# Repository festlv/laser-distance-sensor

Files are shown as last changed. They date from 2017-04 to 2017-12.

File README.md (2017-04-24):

Laser distance sensor
-----------------------

Firmware and hardware design for short-range laser distance sensor.

Preliminary feature list:
  
  * Based on [ST VL53L0X ToF distance sensor](http://www.st.com/en/imaging-and-photonics-solutions/vl53l0x.html),
  * Multiple ranging profiles/modes (default, high accuracy, long range),
  * Up to 2m range (indoors) in long range mode,
  * +/- 3mm accuracy (indoors) in hight accuracy mode,
  * On-board power regulation for 3.3-5.5V input,
  * On-board microcontroller [STM32F042](http://www.st.com/en/microcontrollers/stm32f042f6.html)
  * USB (CDC) and TTL serial outputs,
  * 24x24mm size, M3 mounting holes.

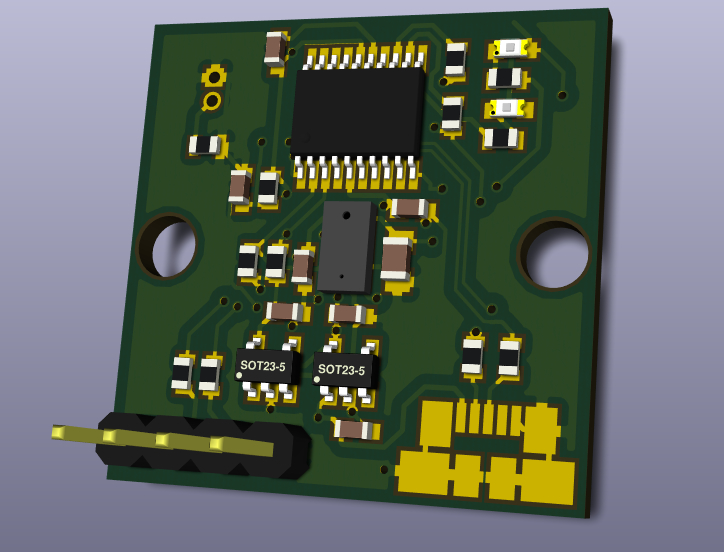
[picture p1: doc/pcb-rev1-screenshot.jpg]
Rev1 PCB render


HERE BE DRAGONS
===================

This project is WIP. Specs might be inaccurate, hardware might let out smoke,
firmware might not compile.

Current status
=================

Hardware: first prototypes have been ordered.
Firmware: waiting on hardware.

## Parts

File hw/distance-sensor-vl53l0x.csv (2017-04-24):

Reference | Value | Footprint | Datasheet | Have on hand | Ordered
U3 | VL53L0X | _sensors:VL53L0X |  | N | Y
C6 | 0.1uF | Capacitors_SMD:C_0603 |  | Y
C7 | 4.7uF | Capacitors_SMD:C_0805 |  | Y
R9 | 4K7 | Resistors_SMD:R_0603 |  | Y
R10 | 4K7 | Resistors_SMD:R_0603 |  | Y
U1 | STM32F042F6Px | Housings_SSOP:TSSOP-20_4.4x6.5mm_Pitch0.65mm |  | N | Y
C3 | 0.1uF | Capacitors_SMD:C_0603 |  | Y
C4 | 1uF | Capacitors_SMD:C_0603 |  | Y
R2 | 4K7 | Resistors_SMD:R_0603 |  | Y
C1 | 0.1uF | Capacitors_SMD:C_0603 |  | Y
J3 | CONN_02X05 | pin_headers_1.27mm:Pin_Header_1.27mm_2x5 |  | Y
R1 | 4K7 | Resistors_SMD:R_0603 |  | Y
R5 | 220R | Resistors_SMD:R_0603 |  | Y
D1 | LED | LEDs:LED_0603 |  | Y
R6 | 220R | Resistors_SMD:R_0603 |  | Y
D2 | LED | LEDs:LED_0603 |  | Y
J2 | USB_OTG | Connectors_Molex:USB_Micro-B_Molex_47346-0001 |  | Y
R3 | 22R | Resistors_SMD:R_0603 |  | Y
R4 | 22R | Resistors_SMD:R_0603 |  | Y
U2 | MIC5504-3.3 | TO_SOT_Packages_SMD:SOT-23-5 |  | N | Y
C2 | 1uF | Capacitors_SMD:C_0603 |  | Y
C5 | 1uF | Capacitors_SMD:C_0603 |  | Y
J1 | DFU | Pin_Headers:Pin_Header_Straight_1x02_Pitch1.27mm |  | Y
J4 | UART | Pin_Headers:Pin_Header_Straight_1x04_Pitch2.54mm |  | Y
R12 | 220R | Resistors_SMD:R_0603 |  | Y
R11 | 220R | Resistors_SMD:R_0603 |  | Y
R8 | 4K7 | Resistors_SMD:R_0603 |  | Y
R7 | 4K7 | Resistors_SMD:R_0603 |  | Y
U4 | MIC5504-2.8 | TO_SOT_Packages_SMD:SOT-23-5 |  | N | Y
C8 | 1uF | Capacitors_SMD:C_0603 |  | Y

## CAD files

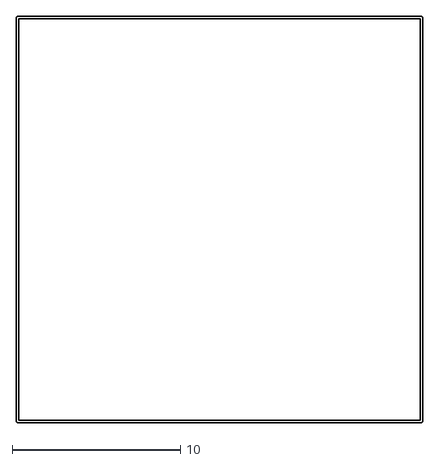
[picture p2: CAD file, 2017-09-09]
hw/out/distance-sensor-vl53l0x-Edge.Cuts.dxf
24.2 x 24.2

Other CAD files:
hw/out/distance-sensor-vl53l0x-F.Paste.dxf

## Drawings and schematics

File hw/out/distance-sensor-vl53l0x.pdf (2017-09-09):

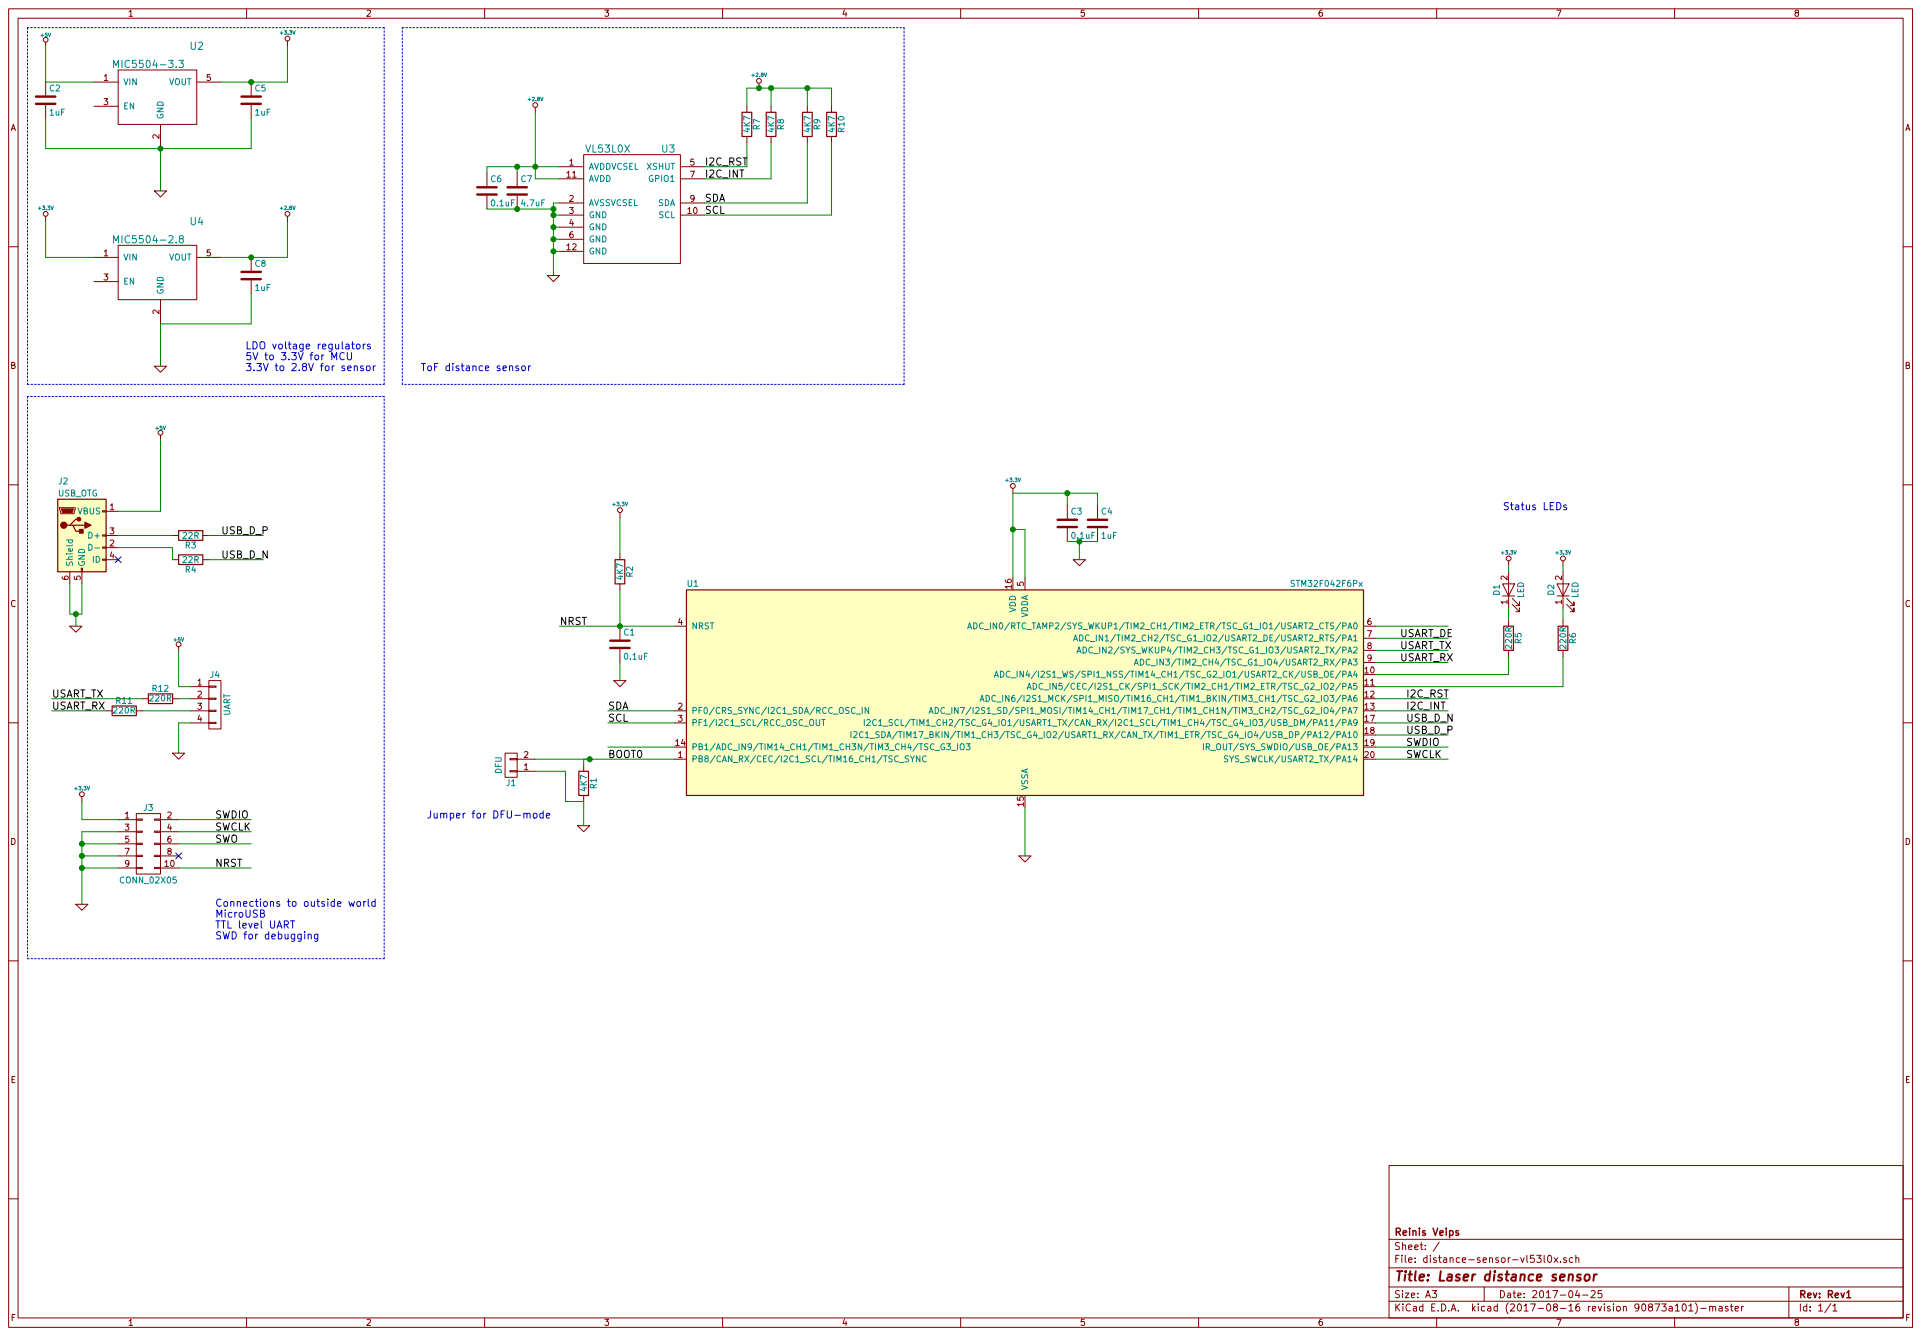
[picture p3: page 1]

3.3V to 2.8V for sensor Connections to outside world

ToF distance sensor Jumper for DFU-mode

USART_DE
USART_TX

I2C_RST
I2C_INT

5 | 6 SWO
9 | 10

MicroUSB
TTL level UART SWD for debugging

Id: 1/1 Title: Laser distance sensor File: distance-sensor-vl53l0x.sch Sheet: / Reinis Veips

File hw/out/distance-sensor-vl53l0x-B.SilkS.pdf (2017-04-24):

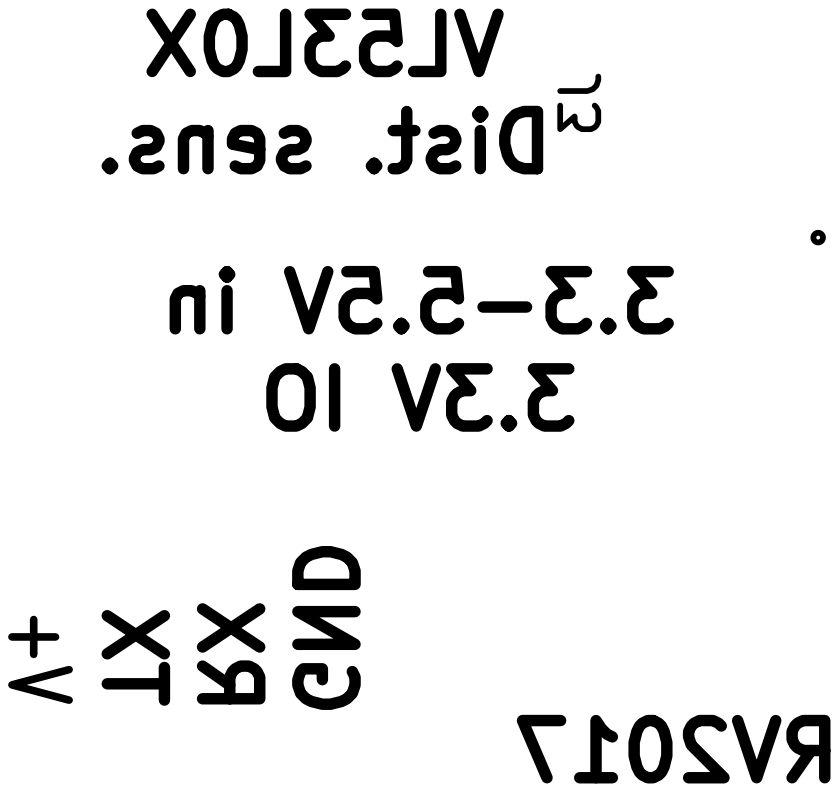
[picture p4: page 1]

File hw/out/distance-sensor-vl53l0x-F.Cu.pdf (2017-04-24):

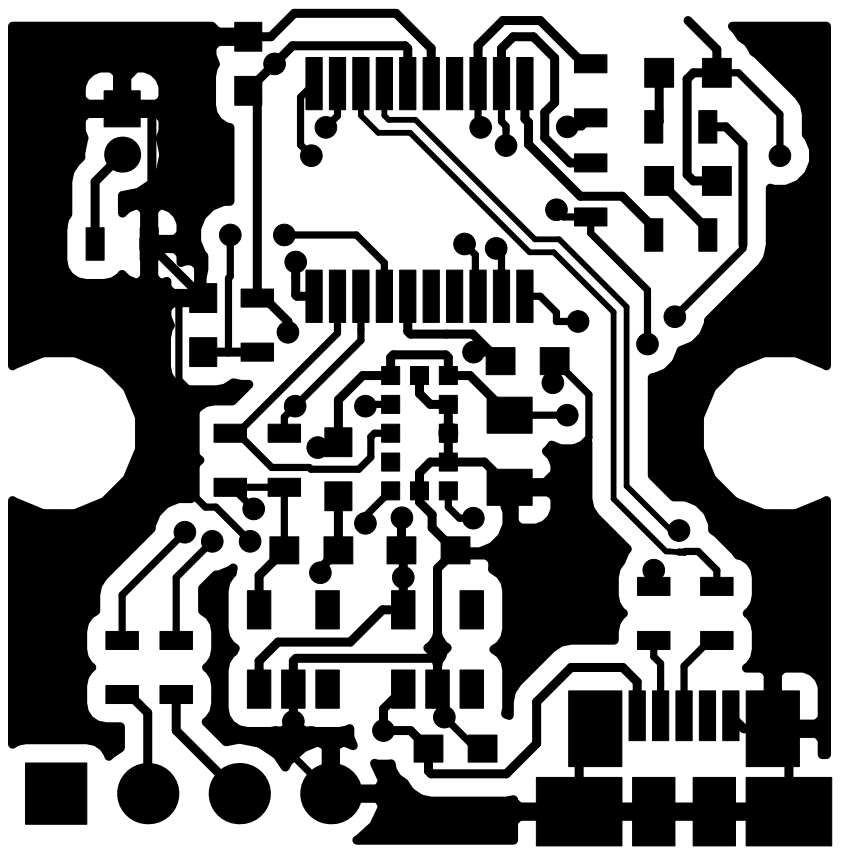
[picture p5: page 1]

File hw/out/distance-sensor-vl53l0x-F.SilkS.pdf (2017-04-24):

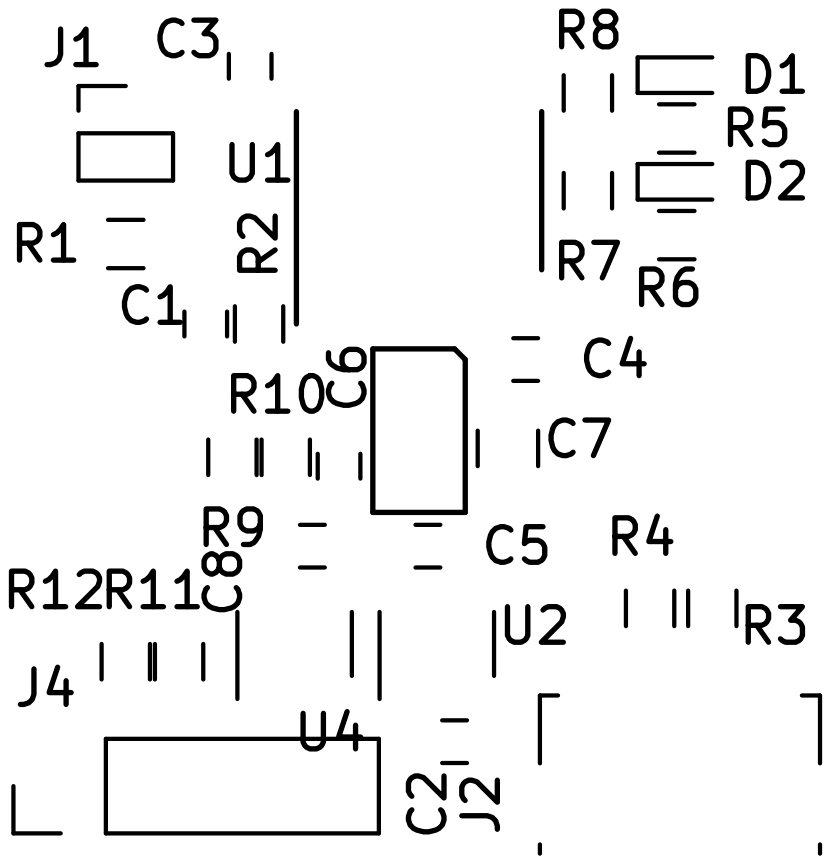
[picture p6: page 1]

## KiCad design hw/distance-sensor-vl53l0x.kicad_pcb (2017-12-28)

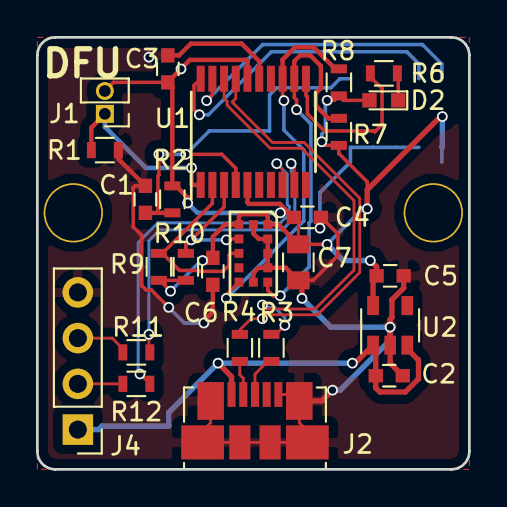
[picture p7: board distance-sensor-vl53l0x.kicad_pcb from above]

Board: 2 copper layers, 24.0 x 24.0 mm, 28 parts (1 on the bottom side), 21 nets.

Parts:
C1, C3, C6: 0.1uF; C_0603
C2, C4, C5: 1uF; C_0603
C7: 4.7uF; C_0805
D2: LED; LED_0603
J1: DFU; Pin_Header_Straight_1x02_Pitch1.27mm
J2: USB_OTG; USB_Micro-B_Molex_47346-0001
J3: CONN_02X05; Pin_Header_1.27mm_2x5
J4: UART; Pin_Header_Straight_1x04_Pitch2.54mm
J101, J102: TEST_1P; Mounting_hole_3mm
R1, R2, R7, R8, R9, R10: 4K7; R_0603
R3, R4: 22R; R_0603
R6, R11, R12: 220R; R_0603
U1: STM32F042F6Px; TSSOP-20_4.4x6.5mm_Pitch0.65mm
U2: MIC5504-3.3; SOT-23-5
U3: VL53L0X

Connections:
+3.3V: C3.1, C4.1, C5.1, C6.1, C7.1, D2.2, J1.2, J3.1, R2.1, R7.1, R8.1, R9.1, R10.1, U1.5, U1.16, U2.5, U3.1, U3.11
+5V: C2.1, J2.1, J4.1, U2.1, U2.3
/BOOT0: J1.1, R1.1, U1.1
/I2C_INT: R8.2, U1.13, U3.7
/I2C_RST: R7.2, U1.12, U3.5
/NRST: C1.1, J3.10, R2.2, U1.4
/SCL: R10.2, U1.3, U3.10
/SDA: R9.2, U1.2, U3.9
/SWCLK: J3.4, U1.20
/SWDIO: J3.2, U1.19
/USART_RX: R11.1, U1.9
/USART_TX: R12.1, U1.8
/USB_D_N: R4.1, U1.17
/USB_D_P: R3.1, U1.18
GND: C1.2, C2.2, C3.2, C4.2, C5.2, C6.2, C7.2, J2.5, J2.6, J3.3, J3.5, J3.7, J3.9, J4.4, R1.2, U1.15, U2.2, U3.2, U3.3, U3.4, U3.6, U3.12
unnamed: D2.1, R6.1
unnamed: J2.2, R4.2
unnamed: J2.3, R3.2
unnamed: J4.2, R12.2
unnamed: J4.3, R11.2
unnamed: R6.2, U1.11

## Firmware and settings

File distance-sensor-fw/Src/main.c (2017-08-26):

/**
  ******************************************************************************
  * File Name          : main.c
  * Description        : Main program body
  ******************************************************************************
  * This notice applies to any and all portions of this file
  * that are not between comment pairs USER CODE BEGIN and
  * USER CODE END. Other portions of this file, whether 
  * inserted by the user or by software development tools
  * are owned by their respective copyright owners.
  *
  * Copyright (c) 2017 STMicroelectronics International N.V. 
  * All rights reserved.
  *
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
  ******************************************************************************
  */
/* Includes ------------------------------------------------------------------*/
#include "main.h"
#include "stm32f0xx_hal.h"
#include "i2c.h"
#include "usart.h"
#include "usb_device.h"
#include "gpio.h"

/* USER CODE BEGIN Includes */
#include "usbd_cdc_if.h"
#include "vl53l0x_api.h"
#include "vl53l0x_platform.h"
#include <stdbool.h>
/* USER CODE END Includes */


/* USER CODE BEGIN PV */

#define MEASUREMENT_RATE_HZ 30
#define USE_STATUS_LED      1



uint8_t last_msg[256];
int last_msg_len = -1;

static void LOG_MSG(const char* msg)
{
    last_msg[0] = '#';
    strncpy(last_msg + 1, msg, sizeof(last_msg) - 3);
    last_msg[sizeof(last_msg) - 1] = '\0';
    int msg_len = strlen(last_msg);
    last_msg[msg_len] = '\n';
    msg_len++;
    last_msg[msg_len] = '\0';
    CDC_Transmit_FS(last_msg, msg_len);
    HAL_UART_Transmit(&huart2, last_msg, msg_len, 5);
    last_msg_len = msg_len;
}
/* USER CODE END PV */

void SystemClock_Config(void);

/* USER CODE BEGIN PFP */

/* USER CODE END PFP */

int main(void)
{

  /* MCU Configuration----------------------------------------------------------*/

  /* Reset of all peripherals, Initializes the Flash interface and the Systick. */
  HAL_Init();

  /* Configure the system clock */
  SystemClock_Config();

  /* Initialize all configured peripherals */
  MX_GPIO_Init();
  MX_I2C1_Init();
  MX_USB_DEVICE_Init();
  MX_USART2_UART_Init();

  /* USER CODE BEGIN 2 */
    bool sensor_error = false;

    //reset sensor
    HAL_GPIO_WritePin(I2C1_RST_GPIO_Port, I2C1_RST_Pin, GPIO_PIN_RESET);
    HAL_Delay(10);
    HAL_GPIO_WritePin(I2C1_RST_GPIO_Port, I2C1_RST_Pin, GPIO_PIN_SET);
    HAL_Delay(5);

    VL53L0X_Dev_t dev;
    dev.addr = 0x52;
    VL53L0X_Error status = VL53L0X_i2c_init();
    status = VL53L0X_DataInit(&dev);
    if (status != VL53L0X_ERROR_NONE) {
        LOG_MSG("data init failed");
        sensor_error = true;
    }

    status = VL53L0X_StaticInit(&dev);
    if (status != VL53L0X_ERROR_NONE) {
        LOG_MSG("static init failed");
        sensor_error = true;
    }

    uint8_t vhv_settings;
    uint8_t phase_cal;
    status = VL53L0X_PerformRefCalibration(&dev, &vhv_settings, &phase_cal);
    if (status != VL53L0X_ERROR_NONE) {
        LOG_MSG("reference calibration failed");
        sensor_error = true;
    }

    uint32_t ref_spad_count;
    uint8_t is_aperture_spads;
    status = VL53L0X_PerformRefSpadManagement(&dev,
        		&ref_spad_count, &is_aperture_spads);
    if (status != VL53L0X_ERROR_NONE) {
        LOG_MSG("spad management failed");
        sensor_error = true;
    }


    status = VL53L0X_SetDeviceMode(&dev, VL53L0X_DEVICEMODE_CONTINUOUS_RANGING);
    if (status != VL53L0X_ERROR_NONE) {
        LOG_MSG("set device mode failed");
        sensor_error = true;
    }

    status = VL53L0X_StartMeasurement(&dev);
    if (status != VL53L0X_ERROR_NONE) { 
        LOG_MSG("start measurement failed");
        sensor_error = true;
    }

    if (sensor_error) {
        HAL_GPIO_WritePin(LED_USR_GPIO_Port, LED_USR_Pin, 0);
    }

  /* USER CODE END 2 */

  /* Infinite loop */
  /* USER CODE BEGIN WHILE */
    while (1)
    {
  /* USER CODE END WHILE */

  /* USER CODE BEGIN 3 */
        if (sensor_error && last_msg_len > 0) {
            //sensor has logged an error, report last error message 
            //in case user has not seen it if using USB
            CDC_Transmit_FS(last_msg, last_msg_len);
            HAL_UART_Transmit(&huart2, last_msg, last_msg_len, 5);
            HAL_Delay(1000);
            continue;
        }

        uint8_t new_data_ready = 0;
        status = VL53L0X_GetMeasurementDataReady(&dev, &new_data_ready);
        if (status != VL53L0X_ERROR_NONE) {
            LOG_MSG("getting measurement data ready flag failed");
        }

        if (new_data_ready) {
            VL53L0X_RangingMeasurementData_t data;
            status = VL53L0X_GetRangingMeasurementData(&dev, &data);
            if (status != VL53L0X_ERROR_NONE)
                LOG_MSG("getting measurement data failed");
#if USE_STATUS_LED
            HAL_GPIO_WritePin(LED_USR_GPIO_Port, LED_USR_Pin, 0);
#endif
            uint8_t buf[32];
            itoa(data.RangeMilliMeter, buf, 10);
            int str_len = strlen(buf);
            buf[str_len] = '\n';
            str_len++;
            CDC_Transmit_FS(buf, str_len);
            HAL_UART_Transmit(&huart2, buf, str_len, 5);
            if (status == VL53L0X_ERROR_NONE)
            {
                status = VL53L0X_ClearInterruptMask(&dev, VL53L0X_REG_SYSTEM_INTERRUPT_GPIO_NEW_SAMPLE_READY);
            }

#if USE_STATUS_LED
            HAL_GPIO_WritePin(LED_USR_GPIO_Port, LED_USR_Pin, 1);
#endif
        }

        HAL_Delay(1000 / MEASUREMENT_RATE_HZ);
    }
  /* USER CODE END 3 */

}

/** System Clock Configuration
*/
void SystemClock_Config(void)
{

  RCC_OscInitTypeDef RCC_OscInitStruct;
  RCC_ClkInitTypeDef RCC_ClkInitStruct;
  RCC_PeriphCLKInitTypeDef PeriphClkInit;

    /**Initializes the CPU, AHB and APB busses clocks 
    */
  RCC_OscInitStruct.OscillatorType = RCC_OSCILLATORTYPE_HSI|RCC_OSCILLATORTYPE_HSI48;
  RCC_OscInitStruct.HSIState = RCC_HSI_ON;
  RCC_OscInitStruct.HSI48State = RCC_HSI48_ON;
  RCC_OscInitStruct.HSICalibrationValue = 16;
  RCC_OscInitStruct.PLL.PLLState = RCC_PLL_NONE;
  if (HAL_RCC_OscConfig(&RCC_OscInitStruct) != HAL_OK)
  {
    _Error_Handler(__FILE__, __LINE__);
  }

    /**Initializes the CPU, AHB and APB busses clocks 
    */
  RCC_ClkInitStruct.ClockType = RCC_CLOCKTYPE_HCLK|RCC_CLOCKTYPE_SYSCLK
                              |RCC_CLOCKTYPE_PCLK1;
  RCC_ClkInitStruct.SYSCLKSource = RCC_SYSCLKSOURCE_HSI48;
  RCC_ClkInitStruct.AHBCLKDivider = RCC_SYSCLK_DIV1;
  RCC_ClkInitStruct.APB1CLKDivider = RCC_HCLK_DIV1;

  if (HAL_RCC_ClockConfig(&RCC_ClkInitStruct, FLASH_LATENCY_1) != HAL_OK)
  {
    _Error_Handler(__FILE__, __LINE__);
  }

  PeriphClkInit.PeriphClockSelection = RCC_PERIPHCLK_USB|RCC_PERIPHCLK_I2C1;
  PeriphClkInit.I2c1ClockSelection = RCC_I2C1CLKSOURCE_HSI;
  PeriphClkInit.UsbClockSelection = RCC_USBCLKSOURCE_HSI48;

  if (HAL_RCCEx_PeriphCLKConfig(&PeriphClkInit) != HAL_OK)
  {
    _Error_Handler(__FILE__, __LINE__);
  }

    /**Configure the Systick interrupt time 
    */
  HAL_SYSTICK_Config(HAL_RCC_GetHCLKFreq()/1000);

    /**Configure the Systick 
    */
  HAL_SYSTICK_CLKSourceConfig(SYSTICK_CLKSOURCE_HCLK);

  /* SysTick_IRQn interrupt configuration */
  HAL_NVIC_SetPriority(SysTick_IRQn, 0, 0);
}

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


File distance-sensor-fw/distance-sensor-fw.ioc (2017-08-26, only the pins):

Mcu.UserName=STM32F042F6Px
PA1.Signal=USART2_DE
PA11.Signal=USB_DM
PA12.Signal=USB_DP
PA13.Signal=SYS_SWDIO
PA14.Signal=SYS_SWCLK
PA2.Signal=USART2_TX
PA3.Signal=USART2_RX
PA4.GPIO_Label=LED_USB
PA4.Signal=GPIO_Output
PA5.GPIO_Label=LED_USR
PA5.Signal=GPIO_Output
PA6.GPIO_Label=I2C1_RST
PA6.Signal=GPIO_Output
PA7.GPIO_Label=I2C1_INT
PA7.Signal=GPXTI7
PB8.GPIO_Label=BOOT0
PB8.Signal=GPIO_Input
PF0-OSC_IN.Signal=I2C1_SDA
PF1-OSC_OUT.Signal=I2C1_SCL

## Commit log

2017-04-24 Rev1 hardware ordered
    [distance-sensor-fw.cfg, distance-sensor-vl53l0x.csv, distance-sensor-vl53l0x.kicad_pcb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]
2017-04-24 Adds README, LICENSE and PCB render.
2017-04-24 Rearranged schematics, PDF output for easier viewing
    [distance-sensor-vl53l0x.sch]
2017-08-24 Integrates VL53L0X driver
2017-09-09 Hardware changes for rev2
    [distance-sensor-vl53l0x-Edge.Cuts.dxf, distance-sensor-vl53l0x-F.Paste.dxf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]
2017-12-28 Change PCB corners to rounded.
    [distance-sensor-vl53l0x-B.Cu.gbr, distance-sensor-vl53l0x-B.Mask.gbr, distance-sensor-vl53l0x-B.SilkS.gbr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]

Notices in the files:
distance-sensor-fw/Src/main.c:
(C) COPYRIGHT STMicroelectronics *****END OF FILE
